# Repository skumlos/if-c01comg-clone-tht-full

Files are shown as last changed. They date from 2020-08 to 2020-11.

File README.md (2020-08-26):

IF-C01COMG Clone board THT Full size

This is a full sized version of the IF-C01COMG board for JVC pro monitors (TM-Hxx50CG) and some others...

It's basically the THT base board I made some years ago with SCART or BNC input and some audio mixing
stuff.

Credit goes to James Vanderloeff for the dual input idea.

You can upload the zip file from the plot directory directly to manufacturers that don't do kicad files directly.

You're welcome to clone, sell, re-design and whatever, see LICENSE.

(2020) Martin Hejnfelt (martin@hejnfelt.com)
This work is free. You can redistribute it and/or modify it under the
terms of the Do What The Fuck You Want To Public License, Version 2,
as published by Sam Hocevar. See the LICENSE file for more details.

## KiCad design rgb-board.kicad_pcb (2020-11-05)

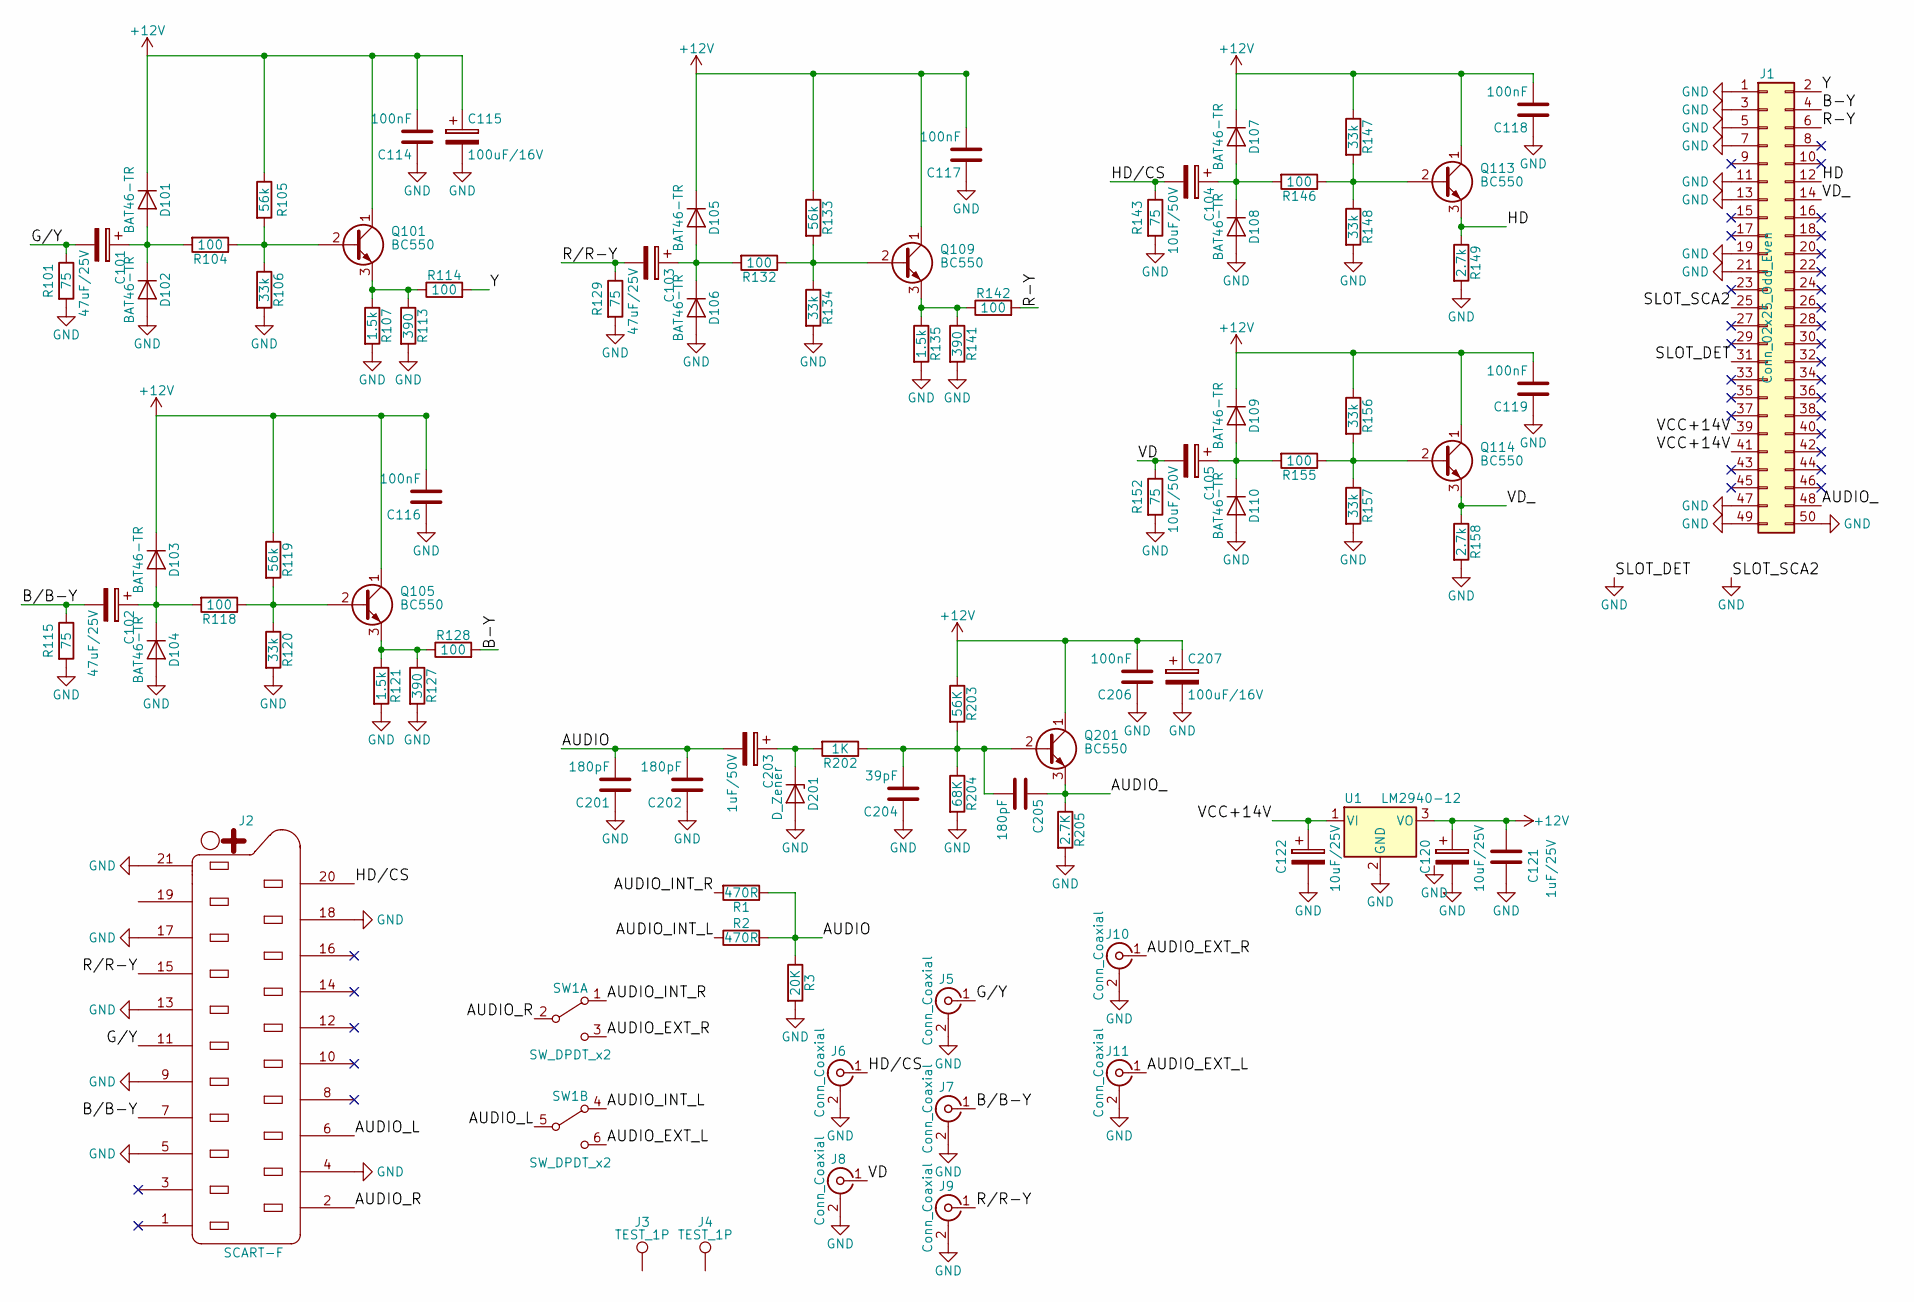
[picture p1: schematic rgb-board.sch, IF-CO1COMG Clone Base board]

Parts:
C101, C102, C103: 47uF/25V; CP_Radial_D5.0mm_P2.50mm
C104, C105: 10uF/50V; CP_Radial_D5.0mm_P2.00mm
C114, C116, C117, C118, C119, C206: 100nF; C_Disc_D3.8mm_W2.6mm_P2.50mm
C115, C207: 100uF/16V; CP_Radial_D6.3mm_P2.50mm
C120, C122: 10uF/25V; CP_Radial_D5.0mm_P2.00mm
C121: 1uF/25V; C_Disc_D5.0mm_W2.5mm_P2.50mm
C201, C202, C205: 180pF; C_Disc_D3.8mm_W2.6mm_P2.50mm
C203: 1uF/50V; CP_Radial_D5.0mm_P2.50mm
C204: 39pF; C_Disc_D3.8mm_W2.6mm_P2.50mm
D101, D102, D103, D104, D105, D106, D107, D108, D109, D110: BAT46-TR; D_DO-35_SOD27_P7.62mm_Horizontal
D201: D_Zener; D_DO-35_SOD27_P7.62mm_Horizontal
J1: Conn_02x25_Odd_Even; Pin_Header_Angled_2x25_Pitch2.54mm
J2: SCART-F; NINIGI-SCART-RA
J3, J4: TEST_1P; MountingHole_3.2mm_M3
J5, J6, J7, J8, J9: Conn_Coaxial; BNC-THT
J10, J11: Conn_Coaxial; RCJ-04X
Q101, Q105, Q109, Q113, Q114, Q201: BC550; TO-92_Molded_Narrow
R1, R2: 470R; R_Axial_DIN0207_L6.3mm_D2.5mm_P7.62mm_Horizontal
R3: 20K; R_Axial_DIN0207_L6.3mm_D2.5mm_P7.62mm_Horizontal
R101, R115, R129, R143, R152: 75; R_Axial_DIN0207_L6.3mm_D2.5mm_P7.62mm_Horizontal
R104, R114, R118, R128, R132, R142, R146, R155: 100; R_Axial_DIN0207_L6.3mm_D2.5mm_P7.62mm_Horizontal
R105, R119, R133: 56k; R_Axial_DIN0207_L6.3mm_D2.5mm_P7.62mm_Horizontal
R106, R120, R134, R147, R148, R156, R157: 33k; R_Axial_DIN0207_L6.3mm_D2.5mm_P7.62mm_Horizontal
R107, R121, R135: 1.5k; R_Axial_DIN0207_L6.3mm_D2.5mm_P7.62mm_Horizontal
R113, R127, R141: 390; R_Axial_DIN0207_L6.3mm_D2.5mm_P7.62mm_Horizontal
R149, R158: 2.7k; R_Axial_DIN0207_L6.3mm_D2.5mm_P7.62mm_Horizontal
R202: 1K; R_Axial_DIN0207_L6.3mm_D2.5mm_P7.62mm_Horizontal
R203: 56K; R_Axial_DIN0207_L6.3mm_D2.5mm_P7.62mm_Horizontal
R204: 68K; R_Axial_DIN0207_L6.3mm_D2.5mm_P7.62mm_Horizontal
R205: 2.7K; R_Axial_DIN0207_L6.3mm_D2.5mm_P7.62mm_Horizontal
SW1: SW_DPDT_x2; LC2259
U1: LM2940-12; TO-220_Horizontal

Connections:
+12V: C114.2, C115.1, C116.2, C117.2, C118.2, C119.2, C120.1, C121.2, C206.2, C207.1, D101.1 (K), D103.1 (K), D105.1 (K), D107.1 (K), D109.1 (K), Q101.1 (C), Q105.1 (C), Q109.1 (C), Q113.1 (C), Q114.1 (C), Q201.1 (C), R105.1, R119.1, R133.1, R147.1, R156.1, R203.1, U1.3 (VO)
/AUDIO: C201.2, C202.2, C203.2, R1.1, R2.2, R3.1
/AUDIO_: C205.1, J1.48, Q201.3 (E), R205.1
/AUDIO_EXT_L: J11.1 (In), SW1.6 (C)
/AUDIO_EXT_R: J10.1 (In), SW1.3 (C)
/AUDIO_INT_L: R2.1, SW1.4 (A)
/AUDIO_INT_R: R1.2, SW1.1 (A)
/AUDIO_L: J2.6, SW1.5 (B)
/AUDIO_R: J2.2, SW1.2 (B)
/B-Y: J1.4, R128.2
/B/B-Y: C102.2, J2.7, J7.1 (In), R115.1
/G/Y: C101.2, J2.11, J5.1 (In), R101.1
/HD: J1.12, Q113.3 (E), R149.1
/HD/CS: C104.2, J2.20, J6.1 (In), R143.1
/R-Y: J1.6, R142.2
/R/R-Y: C103.2, J2.15, J9.1 (In), R129.1
/VCC+14V: C122.1, J1.39, J1.41, U1.1 (VI)
/VD: C105.2, J8.1 (In), R152.1
/VD_: J1.14, Q114.3 (E), R158.1
/Y: J1.2, R114.2
GND: C114.1, C115.2, C116.1, C117.1, C118.1, C119.1, C120.2, C121.1, C122.2, C201.1, C202.1, C204.1, C206.1, C207.2, D102.2 (A), D104.2 (A), D106.2 (A), D108.2 (A), D110.2 (A), D201.2 (A), J1.1, J1.3, J1.5, J1.7, J1.11, J1.13, J1.19, J1.21, J1.25, J1.31, J1.47, J1.49, J1.50, J2.4, J2.5, J2.9, J2.13, J2.17, J2.18, J2.21, J5.2 (Ext), J6.2 (Ext), J7.2 (Ext), J8.2 (Ext), J9.2 (Ext), J10.2 (Ext), J11.2 (Ext), R3.2, R101.2, R106.2, R107.2, R113.2, R115.2, R120.2, R121.2, R127.2, R129.2, R134.2, R135.2, R141.2, R143.2, R148.2, R149.2, R152.2, R157.2, R158.2, R204.2, R205.2, U1.2 (GND)
unnamed: C101.1, D101.2 (A), D102.1 (K), R104.2
unnamed: C102.1, D103.2 (A), D104.1 (K), R118.2
unnamed: C103.1, D105.2 (A), D106.1 (K), R132.2
unnamed: C104.1, D107.2 (A), D108.1 (K), R146.2
unnamed: C105.1, D109.2 (A), D110.1 (K), R155.2
unnamed: C203.1, D201.1 (K), R202.2
unnamed: C204.2, C205.2, Q201.2 (B), R202.1, R203.2, R204.1
unnamed: Q101.2 (B), R104.1, R105.2, R106.1
unnamed: Q101.3 (E), R107.1, R113.1, R114.1
unnamed: Q105.2 (B), R118.1, R119.2, R120.1
unnamed: Q105.3 (E), R121.1, R127.1, R128.1
unnamed: Q109.2 (B), R132.1, R133.2, R134.1
unnamed: Q109.3 (E), R135.1, R141.1, R142.1
unnamed: Q113.2 (B), R146.1, R147.2, R148.1
unnamed: Q114.2 (B), R155.1, R156.2, R157.1

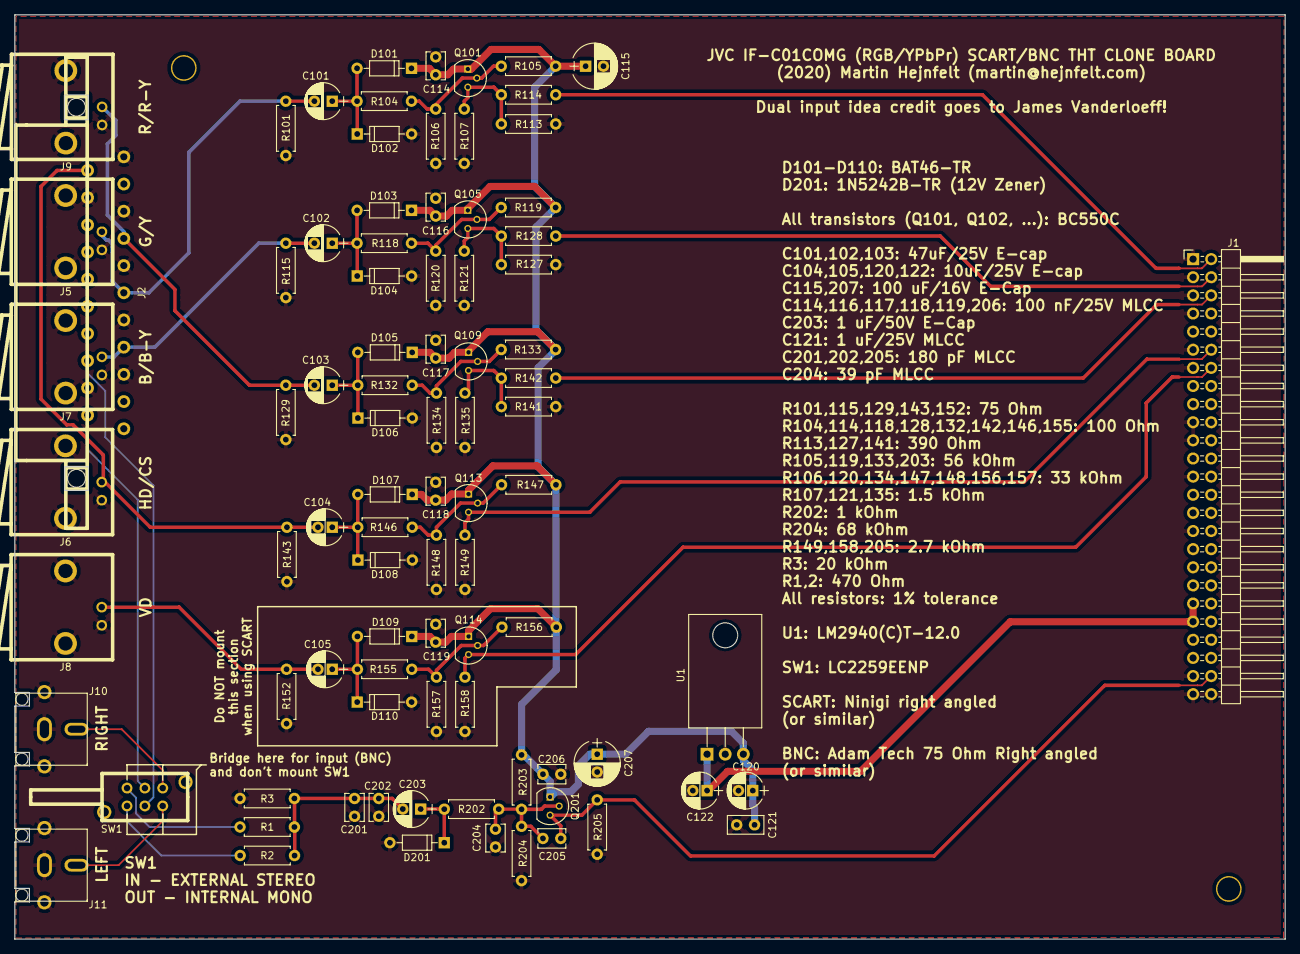
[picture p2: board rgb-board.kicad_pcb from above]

Board: 2 copper layers, 178.0 x 129.5 mm, 89 parts (0 on the bottom side), 36 nets.

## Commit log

2020-08-26 Moved around a bit
    [rgb-board.kicad_pcb]
2020-08-26 Added plot
    [rgb-board-B.Cu.gbr, rgb-board-B.Mask.gbr, rgb-board-B.SilkS.gbr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]
2020-11-05 Fixed missing R155 value
    [rgb-board-B.Cu.gbr, rgb-board-B.Mask.gbr, rgb-board-B.SilkS.gbr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]
